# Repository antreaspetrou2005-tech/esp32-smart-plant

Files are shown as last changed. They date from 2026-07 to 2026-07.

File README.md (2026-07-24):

# 🌱 ESP32 Smart Plant Monitoring System

An IoT-based smart plant monitoring and automatic watering system built using an ESP32.

The system monitors environmental and soil conditions in real time, displays the measurements locally and through a web dashboard, and automatically waters the plant when the soil becomes dry.

---

## 📋 Features

- 🌡 Temperature and humidity monitoring using DHT11
- 🌱 Soil moisture monitoring
- 💧 Automatic watering based on soil moisture level
- 📺 Real-time OLED display
- 🌐 Wi-Fi web dashboard
- 🔘 Manual watering through the web interface
- 🔌 Relay-controlled water pump
- 🛠 Custom-built DC water pump
- 🖥 Custom PCB designed in KiCad

---

## ⚙️ How It Works

The ESP32 continuously reads data from the temperature, humidity, and soil moisture sensors.

When the soil moisture drops below the defined threshold, the ESP32 activates the relay, which powers the water pump.

Sensor readings and system status are displayed on both the OLED screen and the Wi-Fi web dashboard.

**System flow:**

`Sensors → ESP32 → Control Logic → Relay → Water Pump`

`ESP32 → OLED Display + Web Dashboard`

---

## 🛠 Hardware

- ESP32 DevKit V1
- DHT11 Temperature & Humidity Sensor
- Soil Moisture Sensor
- SSD1306 OLED Display
- Relay Module
- Custom-built DC Water Pump
- Custom PCB

---

## 💻 Software

- Arduino IDE
- KiCad 10
- ESP32 Web Server

---

## 🔧 Working Prototype

The complete system was first assembled and tested on a breadboard before moving to the custom PCB design.

Working Prototype

---

## 📺 OLED Display

The OLED provides real-time information including temperature, air humidity, soil moisture, pump status, and plant watering status.

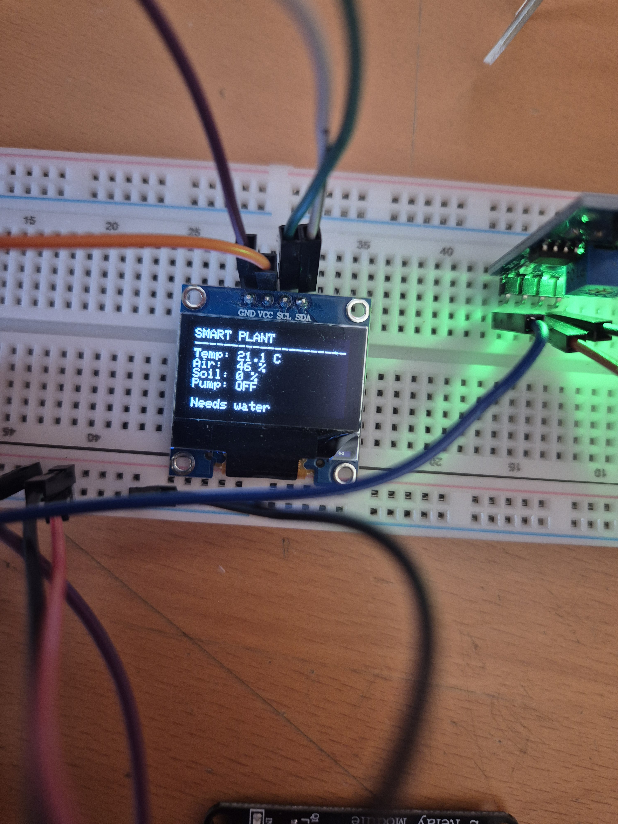
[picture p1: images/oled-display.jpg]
OLED Display


---

## 💧 Custom-built DC Water Pump

Instead of using a ready-made water pump, a small DC water pump was built from scratch for the project.

The pump uses a DC motor, a custom-made impeller, and a handmade housing with inlet and outlet connections.

It is controlled by the ESP32 through a relay and can be activated automatically when the soil moisture level is low.

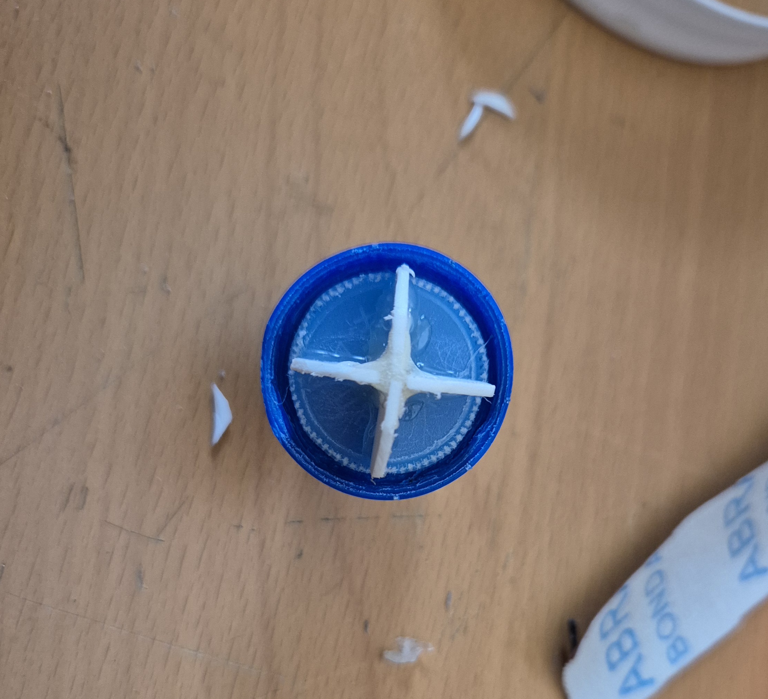
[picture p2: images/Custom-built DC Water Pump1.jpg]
Custom-built DC Water Pump


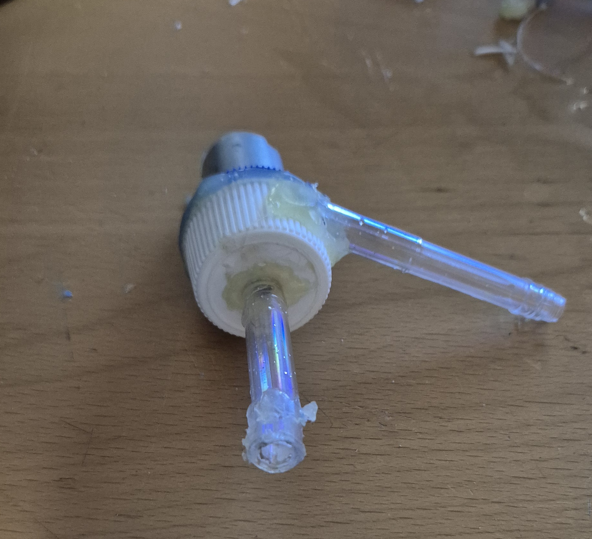
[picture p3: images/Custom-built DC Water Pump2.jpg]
Custom-built DC Water Pump


---

## 📐 Schematic

The complete circuit schematic was designed in KiCad.

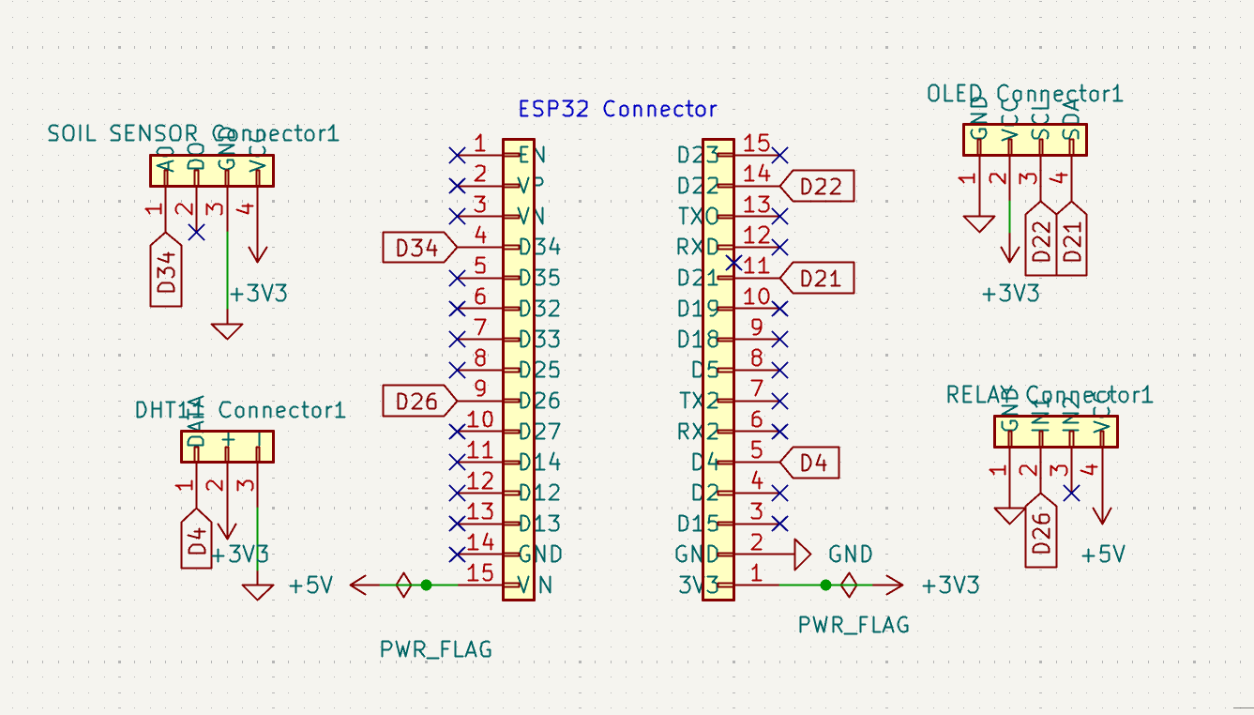
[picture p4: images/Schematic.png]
Schematic


---

## 🖥 PCB Layout

A custom PCB was designed to integrate the ESP32 and the system's sensors and peripherals.

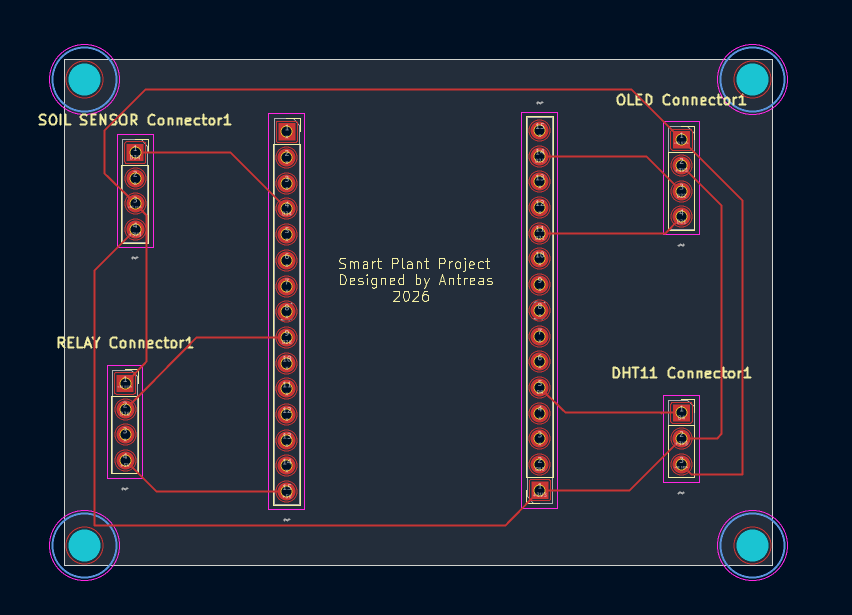
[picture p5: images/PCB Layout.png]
PCB Layout


---

## 📦 3D PCB View

3D visualization of the custom PCB design.

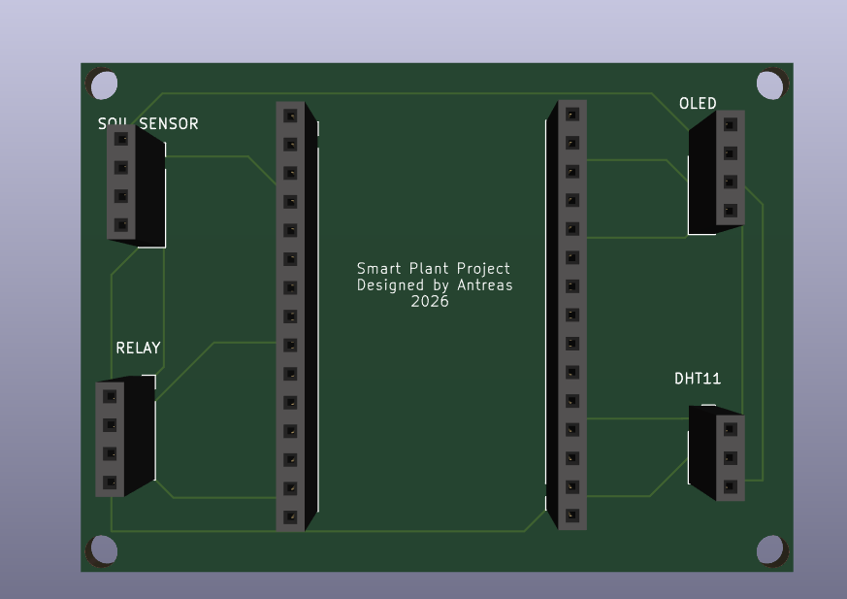
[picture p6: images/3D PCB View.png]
3D PCB View


---

## 🌐 Web Dashboard

The ESP32 hosts a local web interface that allows real-time monitoring of the plant and manual activation of the watering system.

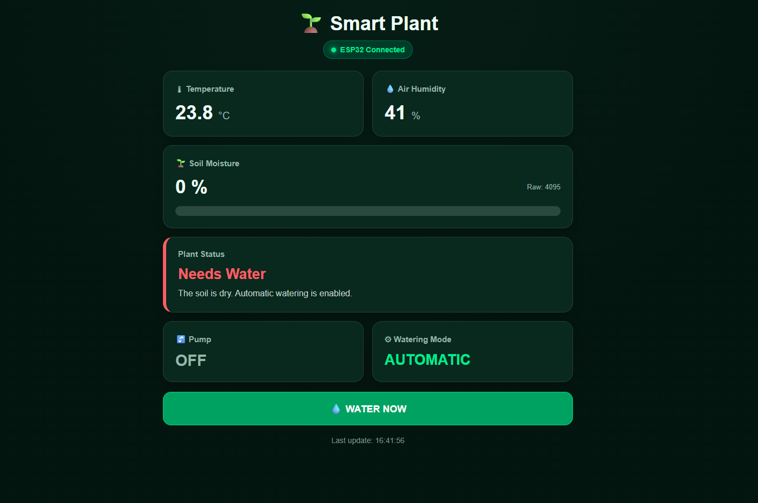
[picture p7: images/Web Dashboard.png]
Smart Plant Web Dashboard


---

## 📁 Repository Structure

- `firmware/` → ESP32 source code
- `pcb/` → KiCad schematic and PCB design files
- `gerber/` → PCB manufacturing files
- `images/` → Project images and screenshots

---

## 🚀 Current Status

- ✅ Breadboard prototype completed
- ✅ Sensors successfully integrated
- ✅ OLED interface completed
- ✅ Wi-Fi web dashboard completed
- ✅ Automatic watering system working
- ✅ Custom water pump built and tested
- ✅ Firmware completed
- ✅ PCB designed in KiCad
- ✅ Gerber manufacturing files generated
- ⏳ Physical PCB manufacturing and assembly coming soon

---

## 👨‍💻 Author

**Antreas Petrou**

Electrical Engineering Student  
Aristotle University of Thessaloniki

---

## 📄 License

This project is licensed under the MIT License.

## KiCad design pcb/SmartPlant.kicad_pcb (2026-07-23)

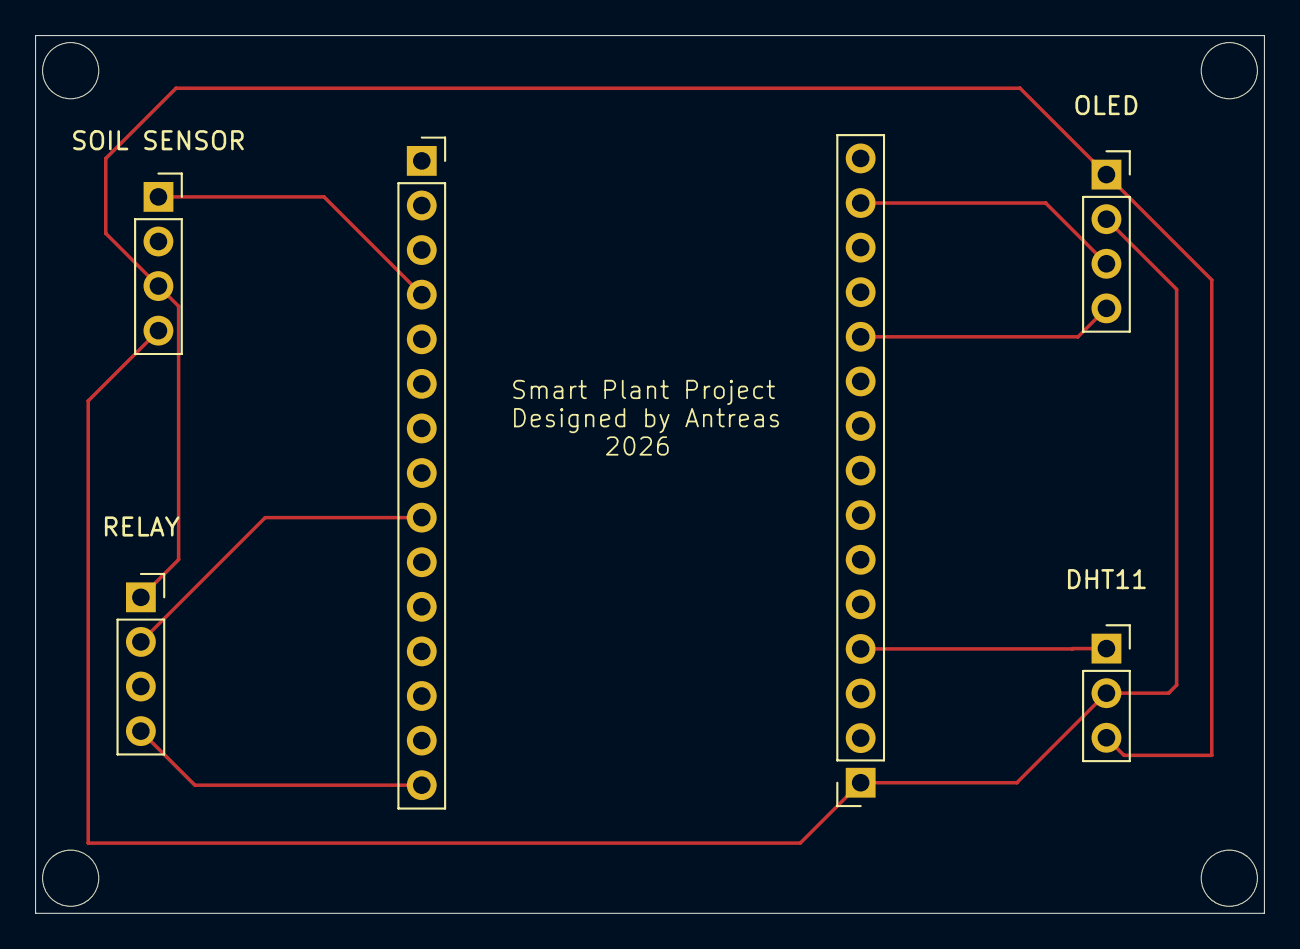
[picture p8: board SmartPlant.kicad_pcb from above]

Board: 2 copper layers, 70.0 x 50.0 mm, 6 parts (0 on the bottom side), 8 nets.

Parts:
DHT11 : PinSocket_1x03_P2.54mm_Vertical
OLED : PinSocket_1x04_P2.54mm_Vertical
RELAY : PinSocket_1x04_P2.54mm_Vertical
SOIL SENSOR : PinSocket_1x04_P2.54mm_Vertical
U1, U2: PinSocket_1x15_P2.54mm_Vertical

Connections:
+3V3: DHT11.2 (+), OLED.2 (VCC), SOIL SENSOR.4 (VCC), U2.1 (3V3)
+5V: RELAY.4 (VCC), U1.15 (VIN)
<NO NET>: DHT11.3 (-), OLED.1 (GND), RELAY.1 (GND), SOIL SENSOR.3 (GND)
D2: DHT11.1 (DATA), U2.4 (D2)
D21: OLED.4 (SDA), U2.11 (D21)
D22: OLED.3 (SCL), U2.14 (D22)
D26: RELAY.2 (IN1), U1.9 (D26)
D34: SOIL SENSOR.1 (A0), U1.4 (D34)

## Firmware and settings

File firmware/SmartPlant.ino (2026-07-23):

#include <WiFi.h>
#include <WebServer.h>
#include <Wire.h>
#include <Adafruit_GFX.h>
#include <Adafruit_SSD1306.h>
#include <DHT.h>

// =====================================================
// 1. WIFI
// =====================================================

const char* WIFI_NAME = "TP-Link_2.4GHz_509B08";
const char* WIFI_PASSWORD = "";

WebServer server(80);

// =====================================================
// 2. OLED
// =====================================================

#define SCREEN_WIDTH 128
#define SCREEN_HEIGHT 64
#define OLED_ADDRESS 0x3C

Adafruit_SSD1306 display(
  SCREEN_WIDTH,
  SCREEN_HEIGHT,
  &Wire,
  -1
);

// =====================================================
// 3. DHT11
// =====================================================

#define DHT_PIN 2
#define DHT_TYPE DHT11

DHT dht(DHT_PIN, DHT_TYPE);

// =====================================================
// 4. SOIL SENSOR
// =====================================================

#define SOIL_PIN 34

// Προσωρινές τιμές βαθμονόμησης.
// Θα τις προσαρμόσουμε αργότερα στον δικό σου αισθητήρα.
const int SOIL_DRY_VALUE = 3800;
const int SOIL_WET_VALUE = 1500;

const int WATERING_THRESHOLD = 30;

// =====================================================
// 5. RELAY ΚΑΙ ΑΝΤΛΙΑ
// =====================================================

#define RELAY_PIN 26

// Τα περισσότερα relay modules λειτουργούν με active LOW.
#define RELAY_ON LOW
#define RELAY_OFF HIGH

// Χρόνος λειτουργίας αντλίας: 3 δευτερόλεπτα
const unsigned long PUMP_DURATION = 3000;

// Χρόνος αναμονής ανάμεσα σε αυτόματα ποτίσματα.
// 3 600 000 ms = 1 ώρα
const unsigned long WATERING_COOLDOWN = 3600000;

// =====================================================
// 6. ΧΡΟΝΙΣΜΟΙ
// =====================================================

const unsigned long SENSOR_INTERVAL = 2000;
const unsigned long OLED_INTERVAL = 500;

unsigned long lastSensorReading = 0;
unsigned long lastOLEDUpdate = 0;
unsigned long pumpStartTime = 0;
unsigned long lastWateringTime = 0;

// =====================================================
// 7. ΜΕΤΑΒΛΗΤΕΣ ΑΙΣΘΗΤΗΡΩΝ
// =====================================================

float temperature = 0.0;
float airHumidity = 0.0;

int soilRawValue = 0;
int soilPercentage = 0;

bool dhtError = true;
bool sensorDataReady = false;

// =====================================================
// 8. ΜΕΤΑΒΛΗΤΕΣ ΑΝΤΛΙΑΣ
// =====================================================

bool pumpIsRunning = false;
bool plantHasBeenWatered = false;
bool lastWateringWasManual = false;

// =====================================================
// 9. ΔΗΛΩΣΕΙΣ ΣΥΝΑΡΤΗΣΕΩΝ
// =====================================================

void connectToWiFi();

void readSensors();
void controlPump();
void startPump(bool manualRequest);
void stopPump();

void updateOLED();

void handleHomePage();
void handleSensorData();
void handleWaterRequest();
void handleNotFound();

const char* getPlantStatus();
const char* getPlantMessage();
const char* getStatusClass();

// =====================================================
// 10. ΙΣΤΟΣΕΛΙΔΑ
// =====================================================

const char WEBPAGE[] PROGMEM = R"HTML(
<!DOCTYPE html>
<html lang="en">

<head>
  <meta charset="UTF-8">

  <meta
    name="viewport"
    content="width=device-width, initial-scale=1"
  >

  <meta
    name="theme-color"
    content="#07150f"
  >

  <title>Smart Plant</title>

  <style>
    :root {
      --background: #07150f;
      --background-light: #0b1d15;
      --card: #11271d;
      --card-border: #254336;
      --text: #f1fff6;
      --muted: #9bb5a7;
      --green: #00e887;
      --green-dark: #009f5c;
      --yellow: #f4b942;
      --red: #ff6262;
      --bar-background: #31483d;
    }

    * {
      box-sizing: border-box;
    }

    body {
      min-height: 100vh;
      margin: 0;
      padding: 24px 16px;
      font-family: Arial, Helvetica, sans-serif;
      color: var(--text);
      background:
        radial-gradient(
          circle at top,
          var(--background-light),
          var(--background) 55%
        );
    }

    .container {
      width: 100%;
      max-width: 760px;
      margin: auto;
    }

    .header {
      margin-bottom: 22px;
      text-align: center;
    }

    .header h1 {
      margin: 0 0 10px;
      font-size: 36px;
    }

    .connection {
      display: inline-flex;
      align-items: center;
      gap: 8px;
      padding: 8px 14px;
      border: 1px solid #176d49;
      border-radius: 999px;
      background: #0b3b29;
      color: var(--green);
      font-size: 14px;
      font-weight: bold;
    }

    .connection.offline {
      border-color: #7a3434;
      background: #3b1c1c;
      color: var(--red);
    }

    .connection-dot {
      width: 9px;
      height: 9px;
      border-radius: 50%;
      background: currentColor;
      box-shadow: 0 0 10px currentColor;
    }

    .grid {
      display: grid;
      grid-template-columns: repeat(2, 1fr);
      gap: 16px;
    }

    .card {
      padding: 22px;
      border: 1px solid var(--card-border);
      border-radius: 18px;
      background: var(--card);
      box-shadow: 0 12px 30px rgba(0, 0, 0, 0.25);
    }

    .full-width {
      grid-column: 1 / -1;
    }

    .card-title {
      margin-bottom: 14px;
      color: var(--muted);
      font-size: 15px;
      font-weight: bold;
    }

    .value {
      font-size: 36px;
      font-weight: bold;
    }

    .unit {
      margin-left: 5px;
      color: var(--muted);
      font-size: 19px;
    }

    .soil-row {
      display: flex;
      align-items: center;
      justify-content: space-between;
      margin-bottom: 16px;
    }

    .soil-value {
      font-size: 35px;
      font-weight: bold;
    }

    .raw-value {
      color: var(--muted);
      font-size: 13px;
    }

    .progress-background {
      width: 100%;
      height: 18px;
      overflow: hidden;
      border-radius: 999px;
      background: var(--bar-background);
    }

    .progress-bar {
      width: 0;
      height: 100%;
      border-radius: inherit;
      background: var(--green);
      transition:
        width 0.5s ease,
        background-color 0.4s ease;
    }

    .status-card {
      border-left: 6px solid var(--green);
      transition: border-color 0.4s ease;
    }

    .status-title {
      margin-bottom: 8px;
      font-size: 27px;
      font-weight: bold;
    }

    .status-message {
      margin: 0;
      color: #c0d0c7;
      line-height: 1.5;
    }

    .healthy {
      color: var(--green);
    }

    .attention {
      color: var(--yellow);
    }

    .dry,
    .error {
      color: var(--red);
    }

    .pump-value {
      font-size: 29px;
      font-weight: bold;
    }

    .pump-off {
      color: var(--muted);
    }

    .pump-on {
      color: var(--green);
      text-shadow: 0 0 10px rgba(0, 232, 135, 0.35);
    }

    .mode-value {
      color: var(--green);
      font-size: 27px;
      font-weight: bold;
    }

    .water-button {
      width: 100%;
      margin-top: 18px;
      padding: 18px;
      border: 1px solid #00d47b;
      border-radius: 15px;
      background: var(--green-dark);
      color: white;
      font-size: 18px;
      font-weight: bold;
      cursor: pointer;
      transition:
        transform 0.2s ease,
        background 0.2s ease,
        box-shadow 0.2s ease;
    }

    .water-button:hover {
      transform: translateY(-2px);
      background: #00b96b;
      box-shadow: 0 8px 24px rgba(0, 232, 135, 0.18);
    }

    .water-button:disabled {
      transform: none;
      border-color: #52695d;
      background: #3b5045;
      color: #a6b5ad;
      cursor: not-allowed;
      box-shadow: none;
    }

    .error-box {
      display: none;
      margin-top: 16px;
      padding: 14px;
      border: 1px solid #8c3f3f;
      border-radius: 12px;
      background: #351a1a;
      color: #ff9a9a;
      text-align: center;
    }

    .footer {
      margin-top: 20px;
      color: #81978b;
      font-size: 14px;
      text-align: center;
    }

    @media (max-width: 600px) {
      body {
        padding: 16px 12px;
      }

      .grid {
        grid-template-columns: 1fr;
      }

      .full-width {
        grid-column: auto;
      }

      .header h1 {
        font-size: 30px;
      }

      .value {
        font-size: 32px;
      }

      .card {
        padding: 19px;
      }
    }
  </style>
</head>

<body>

  <main class="container">

    <header class="header">

      <h1>🌱 Smart Plant</h1>

      <div
        id="connectionStatus"
        class="connection"
      >
        <span class="connection-dot"></span>

        <span id="connectionText">
          Connecting...
        </span>
      </div>

    </header>

    <section class="grid">

      <article class="card">

        <div class="card-title">
          🌡 Temperature
        </div>

        <span
          id="temperature"
          class="value"
        >
          --
        </span>

        <span class="unit">
          °C
        </span>

      </article>

      <article class="card">

        <div class="card-title">
          💧 Air Humidity
        </div>

        <span
          id="humidity"
          class="value"
        >
          --
        </span>

        <span class="unit">
          %
        </span>

      </article>

      <article class="card full-width">

        <div class="card-title">
          🌱 Soil Moisture
        </div>

        <div class="soil-row">

          <div
            id="soilPercentage"
            class="soil-value"
          >
            -- %
          </div>

          <div
            id="soilRaw"
            class="raw-value"
          >
            Raw: --
          </div>

        </div>

        <div class="progress-background">

          <div
            id="soilBar"
            class="progress-bar"
          ></div>

        </div>

      </article>

      <article
        id="plantCard"
        class="card full-width status-card"
      >

        <div class="card-title">
          Plant Status
        </div>

        <div
          id="plantStatus"
          class="status-title"
        >
          Loading...
        </div>

        <p
          id="plantMessage"
          class="status-message"
        >
          Waiting for sensor data...
        </p>

      </article>

      <article class="card">

        <div class="card-title">
          🚰 Pump
        </div>

        <div
          id="pumpStatus"
          class="pump-value pump-off"
        >
          OFF
        </div>

      </article>

      <article class="card">

        <div class="card-title">
          ⚙ Watering Mode
        </div>

        <div class="mode-value">
          AUTOMATIC
        </div>

      </article>

    </section>

    <button
      id="waterButton"
      class="water-button"
      type="button"
    >
      💧 WATER NOW
    </button>

    <div
      id="errorBox"
      class="error-box"
    >
      The page cannot receive data from the ESP32.
    </div>

    <footer class="footer">

      Last update:
      <span id="lastUpdate">--</span>

    </footer>

  </main>

  <script>
    const connectionStatus =
      document.getElementById("connectionStatus");

    const connectionText =
      document.getElementById("connectionText");

    const temperatureElement =
      document.getElementById("temperature");

    const humidityElement =
      document.getElementById("humidity");

    const soilPercentageElement =
      document.getElementById("soilPercentage");

    const soilRawElement =
      document.getElementById("soilRaw");

    const soilBar =
      document.getElementById("soilBar");

    const plantCard =
      document.getElementById("plantCard");

    const plantStatus =
      document.getElementById("plantStatus");

    const plantMessage =
      document.getElementById("plantMessage");

    const pumpStatus =
      document.getElementById("pumpStatus");

    const waterButton =
      document.getElementById("waterButton");

    const errorBox =
      document.getElementById("errorBox");

    const lastUpdate =
      document.getElementById("lastUpdate");

    function setConnectionState(isOnline) {
      if (isOnline) {
        connectionStatus.classList.remove("offline");
        connectionText.textContent = "ESP32 Connected";
        errorBox.style.display = "none";
      } else {
        connectionStatus.classList.add("offline");
        connectionText.textContent = "Connection Error";
        errorBox.style.display = "block";
      }
    }

    function getStatusColor(statusClass) {
      if (statusClass === "healthy") {
        return "#00e887";
      }

      if (statusClass === "attention") {
        return "#f4b942";
      }

      return "#ff6262";
    }

    function updateInterface(data) {
      if (data.dhtError) {
        temperatureElement.textContent = "--";
        humidityElement.textContent = "--";
      } else {
        temperatureElement.textContent =
          Number(data.temperature).toFixed(1);

        humidityElement.textContent =
          Number(data.humidity).toFixed(0);
      }

      soilPercentageElement.textContent =
        data.soil + " %";

      soilRawElement.textContent =
        "Raw: " + data.soilRaw;
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
void loop()
{
  // Πρέπει να εκτελείται συνέχεια ώστε να απαντά
  // το ESP32 στα αιτήματα του browser.
  server.handleClient();

  unsigned long currentTime = millis();

  if (
    currentTime - lastSensorReading
    >= SENSOR_INTERVAL
  )
  {
    lastSensorReading = currentTime;
    readSensors();
  }

  controlPump();

  if (
    currentTime - lastOLEDUpdate
    >= OLED_INTERVAL
  )
  {
    lastOLEDUpdate = currentTime;
    updateOLED();
  }

  // Δίνει λίγο χρόνο στο Wi-Fi stack.
  delay(2);
}

// =====================================================
// 13. WIFI
// =====================================================

void connectToWiFi()
{
  WiFi.mode(WIFI_STA);

  Serial.print("Connecting to Wi-Fi: ");
  Serial.println(WIFI_NAME);

  display.clearDisplay();
  display.setCursor(0, 0);
  display.println("Connecting WiFi...");
  display.display();

  if (strlen(WIFI_PASSWORD) == 0)
  {
    WiFi.begin(WIFI_NAME);
  }
  else
  {
    WiFi.begin(
      WIFI_NAME,
      WIFI_PASSWORD
    );
  }

  unsigned long connectionStart = millis();

  while (WiFi.status() != WL_CONNECTED)
  {
    delay(500);
    Serial.print(".");

    // Αν δεν συνδεθεί σε 30 δευτερόλεπτα,
    // κάνει restart και προσπαθεί ξανά.
    if (
      millis() - connectionStart
      > 30000
    )
    {
      Serial.println();
      Serial.println(
        "Wi-Fi timeout. Restarting..."
      );

      ESP.restart();
    }
  }

  Serial.println();
  Serial.println("Wi-Fi connected.");

  Serial.print("IP address: ");
  Serial.println(WiFi.localIP());

  display.clearDisplay();
  display.setCursor(0, 0);
  display.println("WiFi connected");
  display.println();
  display.println("IP address:");
  display.println(WiFi.localIP());
  display.display();

  delay(2000);
}

// =====================================================
// 14. ΑΝΑΓΝΩΣΗ ΑΙΣΘΗΤΗΡΩΝ
// =====================================================

void readSensors()
{
  float newTemperature =
    dht.readTemperature();

  float newHumidity =
    dht.readHumidity();

  if (
    isnan(newTemperature)
    ||
    isnan(newHumidity)
  )
  {
    dhtError = true;

    Serial.println(
      "DHT11 reading failed."
    );
  }
  else
  {
    dhtError = false;

    temperature =
      newTemperature;

    airHumidity =
      newHumidity;
  }

  soilRawValue =
    analogRead(SOIL_PIN);

  soilPercentage =
    map(
      soilRawValue,
      SOIL_DRY_VALUE,
      SOIL_WET_VALUE,
      0,
      100
    );

  soilPercentage =
    constrain(
      soilPercentage,
      0,
      100
    );

  sensorDataReady = true;

  Serial.println();
  Serial.println("----- SENSOR DATA -----");

  if (!dhtError)
  {
    Serial.print("Temperature: ");
    Serial.print(temperature, 1);
    Serial.println(" C");

    Serial.print("Air humidity: ");
    Serial.print(airHumidity, 1);
    Serial.println(" %");
  }

  Serial.print("Soil raw: ");
  Serial.println(soilRawValue);

  Serial.print("Soil moisture: ");
  Serial.print(soilPercentage);
  Serial.println(" %");
}

// =====================================================
// 15. ΑΥΤΟΜΑΤΟΣ ΕΛΕΓΧΟΣ ΑΝΤΛΙΑΣ
// =====================================================

void controlPump()
{
  if (pumpIsRunning)
  {
    if (
      millis() - pumpStartTime
      >= PUMP_DURATION
    )
    {
      stopPump();
    }

    return;
  }

  // Δεν ποτίζει πριν υπάρξει πραγματική μέτρηση.
  if (!sensorDataReady)
  {
    return;
  }

  bool soilIsDry =
    soilPercentage < WATERING_THRESHOLD;

  bool cooldownHasFinished =
    !plantHasBeenWatered
    ||
    (
      millis() - lastWateringTime
      >= WATERING_COOLDOWN
    );

  if (
    soilIsDry
    &&
    cooldownHasFinished
  )
  {
    Serial.println(
      "Automatic watering started."
    );

    startPump(false);
  }
}

// =====================================================
// 16. ΕΚΚΙΝΗΣΗ ΑΝΤΛΙΑΣ
// =====================================================

void startPump(bool manualRequest)
{
  if (pumpIsRunning)
  {
    return;
  }

  digitalWrite(
    RELAY_PIN,
    RELAY_ON
  );

  pumpIsRunning = true;
  lastWateringWasManual = manualRequest;
  pumpStartTime = millis();

  if (manualRequest)
  {
    Serial.println(
      "Manual watering: Pump ON"
    );
  }
  else
  {
    Serial.println(
      "Automatic watering: Pump ON"
    );
  }
}

// =====================================================
// 17. ΣΤΑΜΑΤΗΜΑ ΑΝΤΛΙΑΣ
// =====================================================

void stopPump()
{
  digitalWrite(
    RELAY_PIN,
    RELAY_OFF
  );

  pumpIsRunning = false;
  plantHasBeenWatered = true;
  lastWateringTime = millis();

  Serial.println("Pump OFF");
}

// =====================================================
// 18. OLED
// =====================================================

void updateOLED()
{
  display.clearDisplay();
  display.setTextColor(SSD1306_WHITE);
  display.setTextSize(1);
  display.setCursor(0, 0);

  display.println("SMART PLANT");
  display.println("---------------------");

  if (dhtError)
  {
    display.println("DHT11: ERROR");
  }
  else
  {
    display.print("Temp: ");
    display.print(temperature, 1);
    display.println(" C");

    display.print("Air:  ");
    display.print(airHumidity, 0);
    display.println(" %");
  }

  display.print("Soil: ");
  display.print(soilPercentage);
  display.println(" %");

  display.print("Pump: ");

  if (pumpIsRunning)
  {
    display.println("ON");
  }
  else
  {
    display.println("OFF");
  }

  display.println();

  if (soilPercentage < 30)
  {
    display.println("Needs water");
  }
  else if (soilPercentage < 60)
  {
    display.println("Check plant");
  }
  else
  {
    display.println("Plant healthy");
  }

  display.display();
}

// =====================================================
// 19. ΚΑΤΑΣΤΑΣΗ ΦΥΤΟΥ
// =====================================================

const char* getPlantStatus()
{
  if (!sensorDataReady)
  {
    return "Waiting";
  }

  if (soilPercentage < 30)
  {
    return "Needs Water";
  }

  if (soilPercentage < 60)
  {
    return "Needs Attention";
  }

  return "Healthy";
}

const char* getPlantMessage()
{
  if (!sensorDataReady)
  {
    return "Waiting for the first sensor measurement.";
  }

  if (soilPercentage < 30)
  {
    return
      "The soil is dry. Automatic watering is enabled.";
  }

  if (soilPercentage < 60)
  {
    return
      "The soil moisture is moderate. Check the plant later.";
  }

  return
    "The soil moisture is at a good level.";
}

const char* getStatusClass()
{
  if (!sensorDataReady)
  {
    return "error";
  }

  if (soilPercentage < 30)
  {
    return "dry";
  }

  if (soilPercentage < 60)
  {
    return "attention";
  }

  return "healthy";
}

// =====================================================
// 20. ΑΠΟΣΤΟΛΗ ΙΣΤΟΣΕΛΙΔΑΣ
// =====================================================

void handleHomePage()
{
  server.sendHeader(
    "Cache-Control",
    "no-store, no-cache, must-revalidate"
  );

  server.send_P(
    200,
    "text/html; charset=utf-8",
    WEBPAGE
  );
}

// =====================================================
// 21. ΑΠΟΣΤΟΛΗ JSON
// =====================================================

void handleSensorData()
{
  char json[650];

  char temperatureText[16];
  char humidityText[16];

  if (dhtError)
  {
    strcpy(
      temperatureText,
      "null"
    );

    strcpy(
      humidityText,
      "null"
    );
  }
  else
  {
    snprintf(
      temperatureText,
      sizeof(temperatureText),
      "%.1f",
      temperature
    );

    snprintf(
      humidityText,
      sizeof(humidityText),
      "%.1f",
      airHumidity
    );
  }

  snprintf(
    json,
    sizeof(json),

    "{"
      "\"temperature\":%s,"
      "\"humidity\":%s,"
      "\"dhtError\":%s,"
      "\"soil\":%d,"
      "\"soilRaw\":%d,"
      "\"pumpOn\":%s,"
      "\"plantStatus\":\"%s\","
      "\"statusClass\":\"%s\","
      "\"plantMessage\":\"%s\""
    "}",

    temperatureText,
    humidityText,
    dhtError ? "true" : "false",
    soilPercentage,
    soilRawValue,
    pumpIsRunning ? "true" : "false",
    getPlantStatus(),
    getStatusClass(),
    getPlantMessage()
  );

  server.sendHeader(
    "Cache-Control",
    "no-store"
  );

  server.send(
    200,
    "application/json; charset=utf-8",
    json
  );

  Serial.println(
    "Browser requested /api/data"
  );
}

// =====================================================
// 22. WATER NOW
// =====================================================

void handleWaterRequest()
{
  if (!pumpIsRunning)
  {
    startPump(true);
  }

  server.sendHeader(
    "Cache-Control",
    "no-store"
  );

  server.send(
    200,
    "application/json",
    "{\"success\":true}"
  );
}
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

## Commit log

2026-07-23 Add firmware, PCB design and Gerber files
    [SmartPlant (1).drl, SmartPlant (1).gbr, SmartPlant (1).gbrjob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]
2026-07-23 Organize project structure
    Reorganize repository into firmware, PCB, Gerber, images and docs folders.
    [SmartPlant (1).drl, SmartPlant (1).gbr, SmartPlant (1).gbrjob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]
2026-07-23 Add KiCad gitignore rules
